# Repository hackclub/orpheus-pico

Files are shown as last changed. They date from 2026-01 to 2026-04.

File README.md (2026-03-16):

# Orpheus Pico 2

### Hack Club's Flagship Microcontroller

banner image

Welcome! This is the newest edition of the Orpheus Pico - an RP2040-based development board, similar to a Raspberry Pi Pico.

## Features

The Orpheus Pico 2 features:

- Identical footprint to the Raspberry Pi Pico
- an RP2040 microcontroller
- 32 addressable GPIO pins
- onboard active-high LED (IO25)
- onboard RGB LED (IO24)
- USB-C connection
- high-current power lines
- and more!

## What's Different?

There have been many major changes from earlier versions of the Orpheus Pico! Several notable ones are:

- epic new silkscreen!
- higher power capability (thickened a bunch of power traces that caused overheating)
- new voltage regulator which doesn't overheat
- dimmed the onboard leds
- significantly improved grounding, meaning lower-impedance path to ground
- made the crystal on the rp2040 more stable
- general cleanup of routing and components

| Previous Orpheus Pico | Latest Orpheus Pico |
| --- | --- |
| old board | new board |

## Usage

Usage of the Orpheus Pico almost completely matches that of a Raspberry Pi Pico. You can use several different frameworks, such as the Pico SDK in C++, Arduino, or Micro/Circuitpython. Some board specific stuff:

- onboard active-high LED on IO25
- onboard RGB LED on IO24
- user-configurable button on IO23 (use a pullup in code)

The RGB led can be controlled as a typical neopixel. You can use libraries like the Adafruit Neopixel library in C++.

---

## Ordering

Want to fabricate your own? Here's a short guide for using JLCPCB to produce assembled versions of these boards!

1. Clone and extract this repository. All production files are found in the /productions directory.
2. Open up JLCPCB, and get to the "Order Now" screen.
3. Drag-and-drop or select through the file menu the orphkicad.zip file in production under the Gerber box at the top.
4. Set PCB settings as desired. We suggest:
    - Quantity - however much you please
    - PCB Color - Black
    - Surface Finish - ENIG (for that gold-colored look)
5. Scroll to the bottom and check "PCB Assembly"
6. Ensure PCBA type is set to Standard (or set to Economic if you don't want the neopixel)
7. Set PCBA Quantity as desired
8. Press "Next" on the right (x2)
9. Upload bom.csv and positions.csv to their corresponding file uploads (BOM File & CPL File)
10. _**Check D2, D3, SW1, SW2, and SW3**_ in BOM confirmation and press "Next"
11. Press "Next" in Component Placements confirmation.
12. You've made it! Review the price and press Save to Cart.

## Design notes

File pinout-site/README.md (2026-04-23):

# Orpheus Pico Pinout

Forked from https://github.com/pinout-xyz/pico.pinout.xyz, this site now hosts the pinout for the Orpheus Pico!

For more info check out https://github.com/hackclub/orpheus-pico

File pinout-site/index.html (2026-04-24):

# Orpheus Pico Pinout

Pin | Name | SPI | I2C | UART | PWM
1 | GP0 | SPI0 RX | I2C0 SDA | UART0 TX | PWM0 A
2 | GP1 | SPI0 CSn | I2C0 SCL | UART0 RX | PWM0 B
3 | Ground
4 | GP2 | SPI0 SCK | I2C1 SDA | UART0 CTS | PWM1 A
5 | GP3 | SPI0 TX | I2C1 SCL | UART0 RTS | PWM1 B
6 | GP4 | SPI0 RX | I2C0 SDA | UART1 TX | PWM2 A
7 | GP5 | SPI0 CSn | I2C0 SCL | UART1 RX | PWM2 B
8 | Ground
9 | GP6 | SPI0 SCK | I2C1 SDA | UART1 CTS | PWM3 A
10 | GP7 | SPI0 TX | I2C1 SCL | UART1 RTS | PWM3 B
11 | GP8 | SPI1 RX | I2C0 SDA | UART1 TX | PWM4 A
12 | GP9 | SPI1 CSn | I2C0 SCL | UART1 RX | PWM4 B
13 | Ground
14 | GP10 | SPI1 SCK | I2C1 SDA | UART1 CTS | PWM5 A
15 | GP11 | SPI1 TX | I2C1 SCL | UART1 RTS | PWM5 B
16 | GP12 | SPI1 RX | I2C0 SDA | UART0 TX | PWM6 A
17 | GP13 | SPI1 CSn | I2C0 SCL | UART0 RX | PWM6 B
18 | Ground
19 | GP14 | SPI1 SCK | I2C1 SDA | UART0 CTS | PWM7 A
20 | GP15 | SPI1 TX | I2C1 SCL | UART0 RTS | PWM7 B

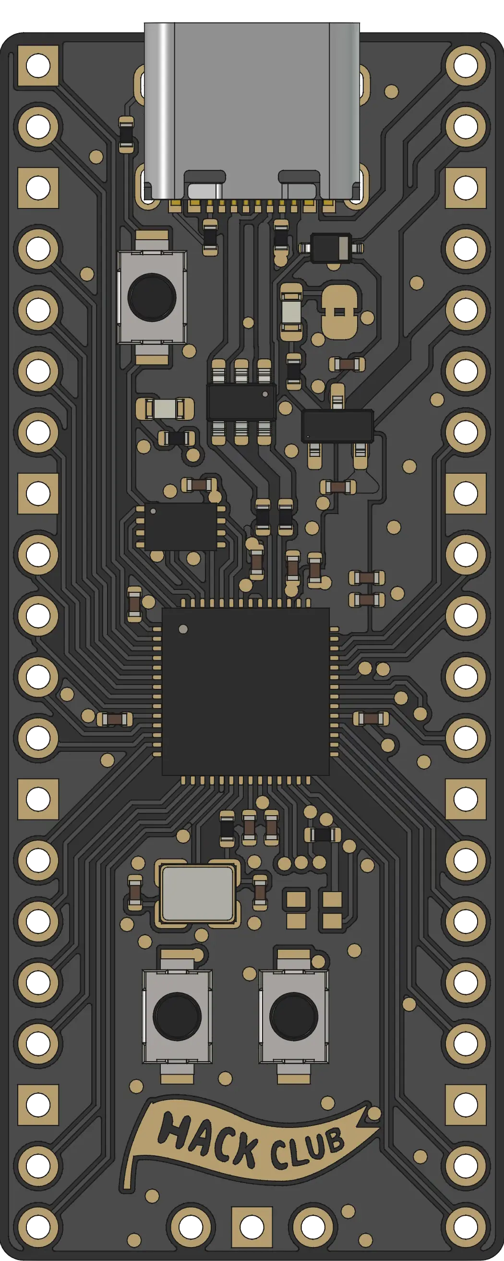
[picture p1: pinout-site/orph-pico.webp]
Orpheus Pico with the micro USB port facing upwards, standing face-up on its GPIO pins.


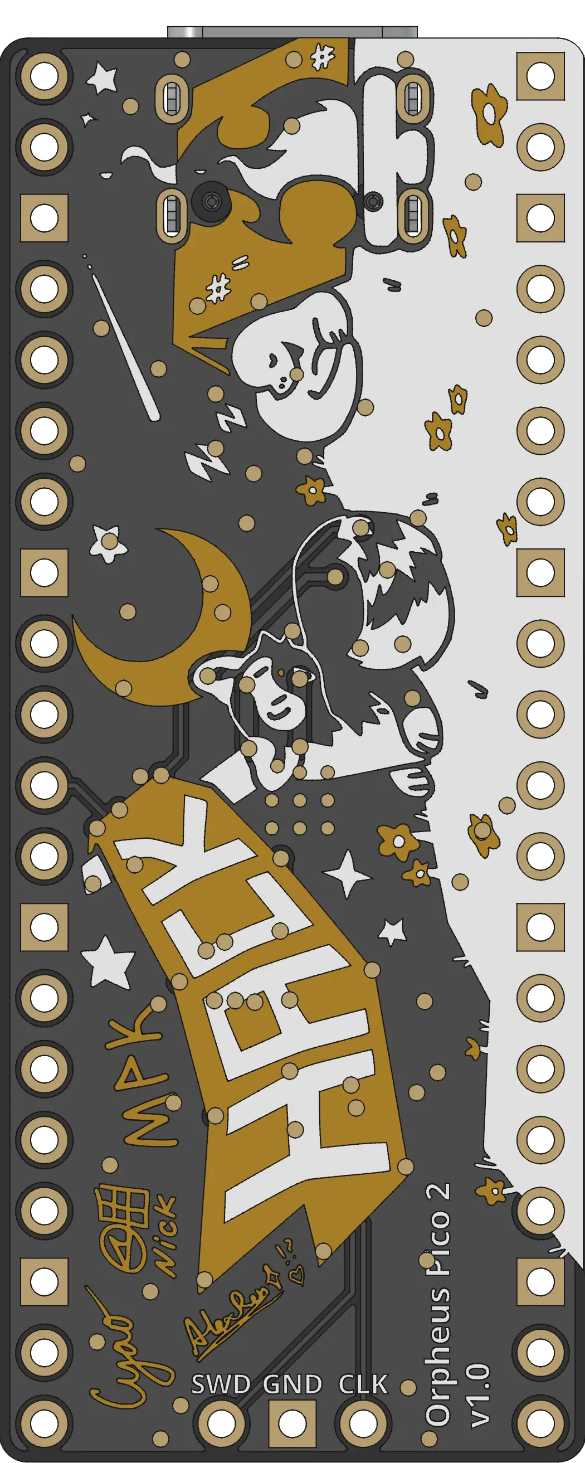
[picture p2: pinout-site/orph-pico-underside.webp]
Orpheus Pico with the micro USB port facing downwards, standing bottom-up on its GPIO pins.


Pin | Name/ADC | SPI | I2C | UART | PWM
40 | VBUS 5V
39 | VSYS 5V*
38 | Ground
37 | N/C
36 | 3V3 Out
35 | N/C
34 | GP28 A2 | SPI1 RX | I2C0 SDA | UART0 TX | PWM6 A
33 | Ground
32 | GP27 A1 | SPI1 TX | I2C1 SCL | UART1 RTS | PWM5 B
31 | GP26 A0 | SPI1 SCK | I2C1 SDA | UART1 CTS | PWM5 A
30 | RUN
29 | GP22 | SPI0 SCK | I2C1 SDA | UART1 CTS | PWM3 A
28 | Ground
27 | GP21 | SPI0 CSn | I2C0 SCL | UART1 RX | PWM2 B
26 | GP20 | SPI0 RX | I2C0 SDA | UART1 TX | PWM2 A
25 | GP19 | SPI0 TX | I2C1 SCL | UART0 RTS | PWM1 B
24 | GP18 | SPI0 SCK | I2C1 SDA | UART0 CTS | PWM1 A
23 | Ground
22 | GP17 | SPI0 CSn | I2C0 SCL | UART0 RX | PWM0 B
21 | GP16 | SPI0 RX | I2C0 SDA | UART0 TX | PWM0 A

SWCLK | GND | SWDIO

Pin | Function | Notes
VSYS | System voltage in/out | *5V out when powered by USB (diode to VBUS), 3.5V to 5.5V in if powered externally
3V3 Out | Chip 3V3 supply | Can be used to power external circuitry, recommended to keep the load less than 200mA
GP23 | User button | LOW when pressed, normally floating.
GP24 | Neopixel | WS2812B user neopixel
GP25 | User LED

RP2040 Datasheet (https://datasheets.raspberrypi.com/rp2040/rp2040-datasheet.pdf) | Getting Started Guide (https://datasheets.raspberrypi.com/pico/getting-started-with-pico.pdf) | Raspberry Pi Forum (https://forums.raspberrypi.com/viewforum.php?f=143) | Slack (https://hackclub.enterprise.slack.com/archives/C056AMWSFKJ)

This interactive, accessible & beautiful GPIO pinout and pin function guide was originally made by @Gadgetoid (https://fosstodon.org/@gadgetoid), forked for the Orpheus Pico.

Want to help them out? Send a PR (https://github.com/pinout-xyz/pico.pinout.xyz), or toss them some coin via Ko-Fi (https://ko-fi.com/gadgetoid), GitHub (https://github.com/sponsors/Gadgetoid) or Patreon (https://www.patreon.com/gadgetoid).

The Orpheus Pico is designed by Nick (https://github.com/autowattage), Max (https://github.com/mpkendall) & Cyao (https://github.com/cheyao).

This interactive, accessible & beautiful pico.pinout.xyz fork is maintained on TODO

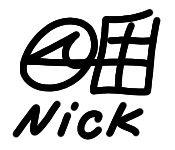
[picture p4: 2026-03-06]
assets/bunnyguy.png

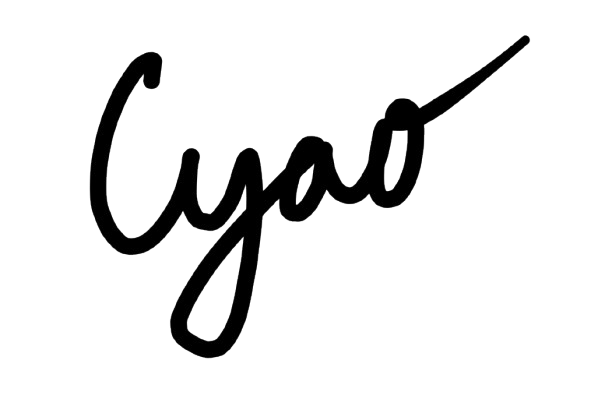
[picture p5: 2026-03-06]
assets/cyao.png

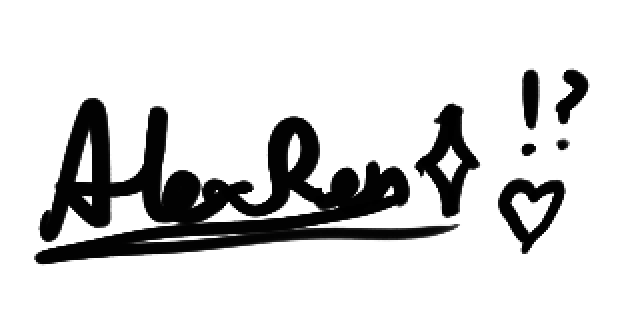
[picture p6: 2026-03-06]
assets/alexren.png

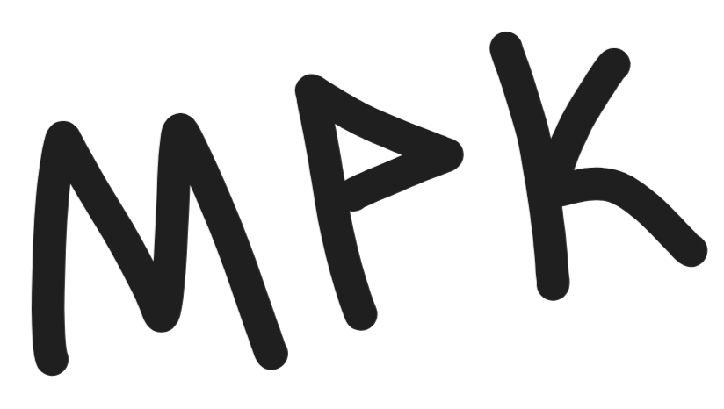
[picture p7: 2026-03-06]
assets/mpk.png

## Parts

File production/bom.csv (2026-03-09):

Designator | Footprint | Quantity | Value | LCSC Part #
C1, C13, C14, C2, C3, C4, C5, C6, C8 | 0402 | 9 | 100nF | C1525
C10, C9 | 0402 | 2 | 15pF | C1548
C11, C17, C18, C7 | 0402 | 4 | 1uF | C52923
D1 | D_SOD-323 | 1 | 1N5819WS | C191023
D2 | 0603 | 1 | LED_PWR | C2286
D3 | 0603 | 1 | LED_USR | C2286
D4 | LED-SMD_4P-L1.6-W1.5_XL-1615RGBC-WS2812B | 1 | LED_RGB | C5349954
J1 | USB-C-SMD_TYPE-C-6PIN-2MD-073 | 1 | USB 2.0 | C2765186
R10, R2, R7, R8, R9 | 0402 | 5 | 1K | C11702
R3, R4 | 0402 | 2 | 33R | C25105
R5, R6 | 0402 | 2 | 5K1 | C25905
SW1 | SW-SMD_L3.9-W3.0-P4.45 | 1 | BTN_BOOT | C455280
SW2 | SW-SMD_L3.9-W3.0-P4.45 | 1 | BTN_RST | C455280
SW3 | SW-SMD_L3.9-W3.0-P4.45 | 1 | BTN_USR | C455280
U1 | QFN-56-1EP_7x7mm_P0.4mm_EP3.2x3.2mm | 1 | RP2040 | C2040
U2 | Winbond_USON-8-1EP_3x2mm_P0.5mm_EP0.2x1.6mm | 1 | W25Q16JVUXIQ | C2843335
U3 | SOT-23-6 | 1 | USBLC6-2SC6 | C5180249
U5 | SOT-23-3 | 1 | XC6206PxxxMR | C5446
Y1 | Crystal_SMD_3225-4Pin_3.2x2.5mm | 1 | X322512MOB4SI 12pF | C70565

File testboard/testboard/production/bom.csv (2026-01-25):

Designator | Footprint | Quantity | Value | LCSC Part #
D1, D10, D11, D12, D13, D14, D15, D16, D17, D18, D19, D2, D20, D21, D22, D23, D24, D25, D27, D29, D3, D30, D31, D33, D4, D5, D6, D7, D8, D9 | 0603 | 30 | LED | C2290
R1, R10, R11, R12, R13, R14, R15, R16, R17, R18, R19, R2, R20, R21, R22, R23, R24, R25, R26, R27, R28, R29, R3, R31, R4, R5, R6, R7, R8, R9 | 0603 | 30 | 680 | C23228
R32 | TO-263-2 | 1 | 1R 50W | C39221240

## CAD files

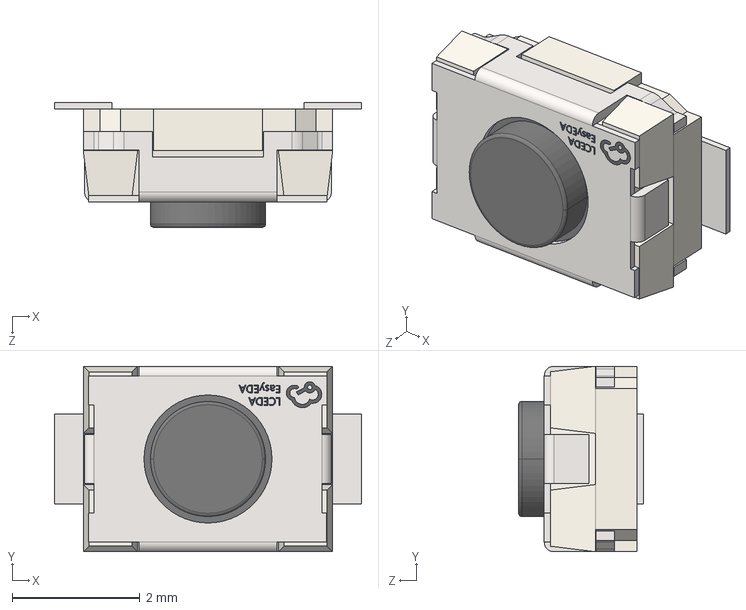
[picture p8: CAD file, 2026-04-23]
assets/SW-SMD_L3.9-W2.9-H2.0-LS4.8.step
4.80 x 2.90 x 1.95 mm

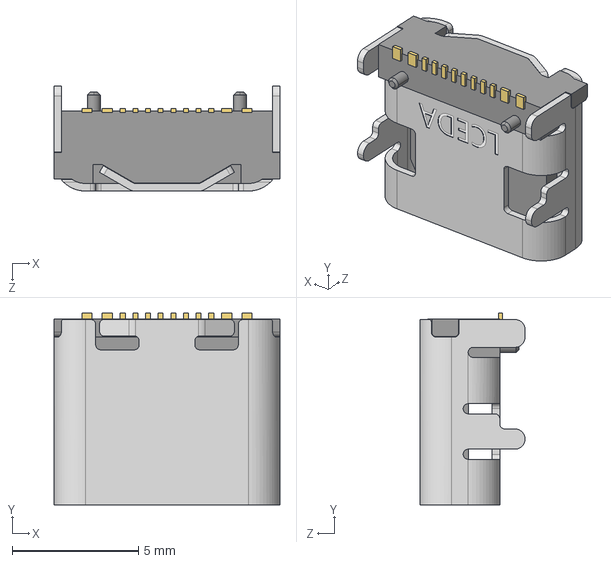
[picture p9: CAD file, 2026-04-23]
assets/USB-C-SMD_TYPE-C-6PIN-2MD-073.step
8.94 x 7.58 x 4.16 mm

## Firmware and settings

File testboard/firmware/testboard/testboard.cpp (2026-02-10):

#include <stdio.h>
#include "pico/stdlib.h"
#include "Adafruit_NeoPixel.hpp"

const int NEOPIXEL = 24;

int gpios[] = {
    0, 1, 2, 3, 4, 5, 6, 7, 8, 9,
    10, 11, 12, 13, 14, 15, 16, 17,
    18, 19, 20, 21, 22, 23, 26, 27, 28
};

int config_leds(void) {
    for(int i = 0; i < sizeof(gpios)/sizeof(gpios[0]); i++) {
        gpio_init(gpios[i]);
        gpio_set_dir(gpios[i], GPIO_OUT);
    }
    return PICO_OK;
}

int main()
{
    stdio_init_all();
    printf("configuring leds\n");
    int result = config_leds();
    hard_assert(result == PICO_OK);
    printf("leds configured, turning pins on\n");

    Adafruit_NeoPixel pixels(1, NEOPIXEL, NEO_GRB + NEO_KHZ800);
    pixels.begin();

    while (true) {
        for(int i = 0; i < sizeof(gpios)/sizeof(gpios[0]); i++) { //active low
            printf("turning on pin %d\n", gpios[i]);
            gpio_put(gpios[i], 0);
            if(gpios[i] == 23) {gpio_put(gpios[i], 1);}
            sleep_ms(150);
        }
        for(int i = 0; i < sizeof(gpios)/sizeof(gpios[0]); i++) {
            printf("turning off pin %d\n", gpios[i]);
            gpio_put(gpios[i], 1);
            if(gpios[i] == 23) {gpio_put(gpios[i], 0);}
            sleep_ms(300);
        }

        for (int i = 0; i < 10; ++i) {
            pixels.setPixelColor(0, pixels.Color((i%3)*150, ((i+1)%3)*150 ,((i+2)%3)*150));
            pixels.show();
            sleep_ms(300);
        }
    }

}

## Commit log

2026-01-10 Change converter to XC6206
    [orphkicad.kicad_pcb, orphkicad.kicad_sch]
2026-01-10 Continue to clean up traces
    [orphkicad.kicad_pcb]
2026-01-18 improve grounding
    [orphkicad.kicad_pcb]
2026-01-18 Improve board
    [orphkicad.kicad_pcb, orphkicad.kicad_sch]
2026-01-18 first pass of lcsc
    [orphkicad.kicad_sch]
2026-01-19 Change LCSC id, move trace, add gnd via
    [orphkicad.kicad_pcb, orphkicad.kicad_sch]
2026-01-19 Add Nick's silkscreen!
    [orphkicad.kicad_pcb]
2026-01-19 Fix SWD silkscreen alignment
    [orphkicad.kicad_pcb]
2026-01-24 production files!
    [BOM-orphkicad.csv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]
2026-01-24 27 -> 33 ohm resistors
    [orphkicad.kicad_sch]
2026-01-25 make io22 and 26 not cut off
    [bom.csv, designators.csv, orphkicad.kicad_pcb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]
2026-02-03 Remove soldermask expansion on pin headers and fix false positive DRC errors
    [orphkicad.kicad_pcb, orphkicad.kicad_sch]
2026-02-14 new gerbers
    [bom.csv, designators.csv, positions.csv]
2026-03-06 added in logos
    [orphkicad.kicad_pcb]
2026-03-06 added my own logo! someone plz sanity check
    [orphkicad.kicad_pcb]
2026-03-07 Pretty up schematic and make PCB footprints up-to-date
    [orphkicad.kicad_pcb, orphkicad.kicad_sch]
2026-03-09 new prod *hopefully* gerbers!
    [bom.csv, designators.csv, orphkicad.kicad_pcb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]
2026-03-16 seamless ordering :yay:
    [orphkicad.kicad_pcb, orphkicad.kicad_sch, positions.csv]
2026-04-23 Add all 3D models
    [SW-SMD_L3.9-W2.9-H2.0-LS4.8.step, USB-C-SMD_TYPE-C-6PIN-2MD-073.step, orphkicad.kicad_pcb]
2026-04-23 Pinout site
    [orphkicad-B_Mask.dxf, orphkicad-B_Silkscreen.dxf, orphkicad.kicad_pcb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]
2026-04-23 Remove prod dxf files
    [orphkicad-B_Mask.dxf, orphkicad-B_Silkscreen.dxf]
